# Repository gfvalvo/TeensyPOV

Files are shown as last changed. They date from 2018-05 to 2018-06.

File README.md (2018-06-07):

# TeensyPOV:

## POV Project on Teensy 3.2 - WORK IN PROGRESS

Library for POV (Persistence of Vision) display using Teensy 3.2 board and Adafuit DotStar LEDs (APA102). Descriptions of the hardware (including schematics and PWB) are in the Hardware folder.
The library is configured to support up to 48 LEDs in the string and up to 512 angular positions (~0.7 degree resolution). These positions are referred to as "segments" in the code and description below.
## Sample Images:
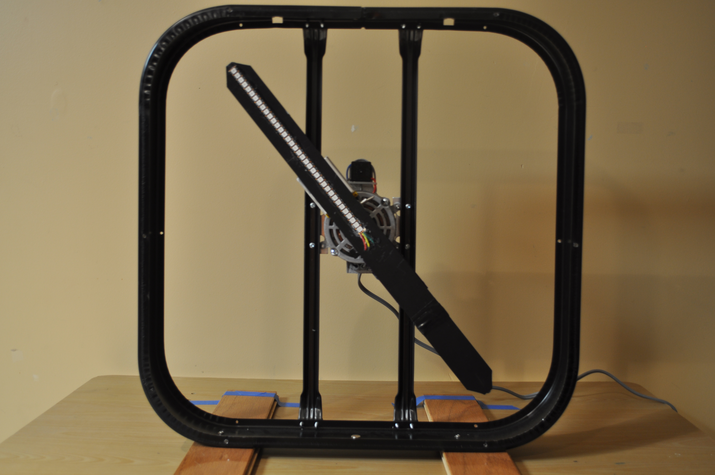
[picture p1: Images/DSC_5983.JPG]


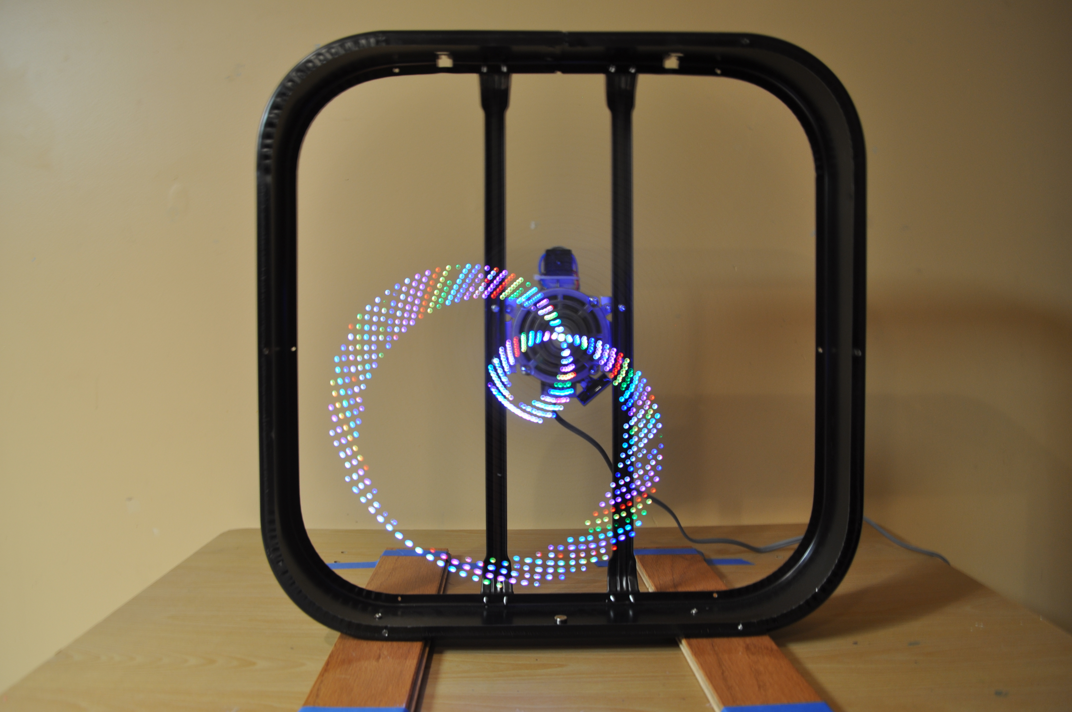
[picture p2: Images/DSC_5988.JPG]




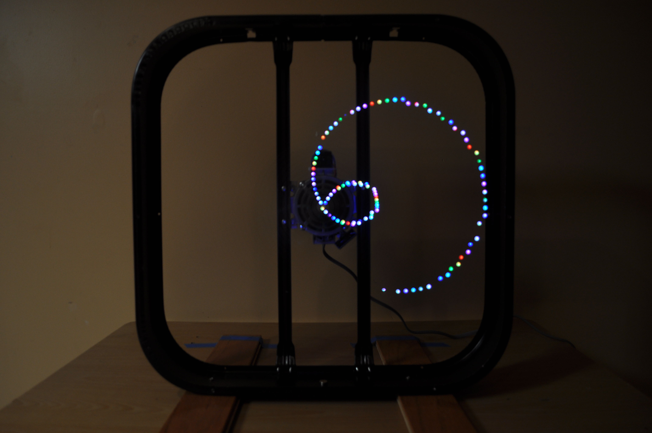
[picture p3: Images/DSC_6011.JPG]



[Video of POV in Action](https://youtu.be/CiRSouhlJos)

Note that interaction between the video's frame rate and the LED refresh rate causes some artifacts that aren't really there when you view the POV in person.

## Library Description:
Code in this library directly manipulates the Teensy processor's Programmable Interrupt Timers. Thus, it is incompatible with any code that uses these timers directly or indirectly via the Teensyduino IntervalTimer class.

All of the following class methods are demonstrated in the example sketches.
### Classes:
#### Class TeensyPOV
This class interfaces with the hardware and controls the LEDs to produce the POV display. All methods in this class are static. Thus there is no need to instantiate an object of this type.
#### Public TeensyPOV Members Functions:
****Initialize the T3.2 hardware needed for the POV Display****

    bool povSetup(uint8_t hPin, CRGB *ledPtr, uint8_t num)
**Arguments:**
 - **uint8_t hPin** - Hardware pin that the Hall Effect Sensor is connected to.
 - **CRGB \*ledPtr** - Pointer to an array of FastLED CRGB objects. These objects should be registered with the FastLED library before calling povSetup.
 - **uint8_t num** - Number LEDs in the array
 
****Check if Rotation Speed is High Enough for POV Display****

    bool rpmGood(void) 

****Get Number of Segments in the Currently Active POV Display.****

    uint16_t getNumSegments(void)

****Get Number of Teensy 3.2 PIT Ticks that Occurred During the Blade's last Rotation Period. On a 96 MHz T3.2 there are 48,000,000 Ticks per Second.****

    uint32_t getLastRotationCount(void)

****Set the color of an LED directly on the display.****

    void setPixel(uint16_t segment, uint16_t pixel, uint32_t value)

**Arguments:**

- **uint16_t segment** - Rotational segment of the LED, counted clockwise from Top Dead Center. Value between 0 and (Number of Segments)-1
- **uint16_t pixel** - Radial position of the LED, 0 = innermost.
- **uint32_t value** - Color of the LED expressed as index into current Palette.

#### Public TeensyPOV Data Members:

Defined constants that can be used in calls to TeensyPovDisplay methods (see **Class TeensyPovDisplay**):
```
static const uint8_t LOG_2_SEGMENTS = 1;
static const uint8_t LOG_4_SEGMENTS = 2;
static const uint8_t LOG_8_SEGMENTS = 3;
static const uint8_t LOG_16_SEGMENTS = 4;
static const uint8_t LOG_32_SEGMENTS = 5;
static const uint8_t LOG_64_SEGMENTS = 6;
static const uint8_t LOG_128_SEGMENTS = 7;
static const uint8_t LOG_256_SEGMENTS = 8;
static const uint8_t LOG_512_SEGMENTS = 9;

static const uint8_t COLOR_BITS_1 = 1;
static const uint8_t COLOR_BITS_2 = 2;
static const uint8_t COLOR_BITS_4 = 4;
static const uint8_t COLOR_BITS_8 = 8;
```
#### Class TeensyPovDisplay
This class allows the user to define POV images to be displayed. There can be multiple instances of this class defining different images. Only one is actively displayed at a time.
#### Public TeensyPovDisplay Members Functions:
****Constructor.****
````
TeensyPovDisplay()
````
****Load an empty TeensyPovDisplay object. Would be used if no bitmap image or text is desired. Pixels would be set by the main program using the setLed() method.****
````
void load(void)
````
****Load a TeensyPovDisplay object with a bit pattern image.****
````
void load(const LedArrayStruct *pattern)
````

**Arguments:**

- **const LedArrayStruct \*pattern** - Pointer to the image structure. The struct pointed to must be static or global. See below for definition of the LedArrayStruct structure.

****Load a TeensyPovDisplay object with text strings.****
````
void load(const DisplayStringSpec *strArray, uint8_t n)
````
**Arguments:**
- **const DisplayStringSpec \*strArray** - Pointer to an array of DisplayStringSpec structures. The array pointed to must be static or global. See below for definition of the DisplayStringSpec structure.
- **uint8_t n** - Number of DisplayStringSpec structures in the array.

****Load a TeensyPovDisplay object with a bit pattern image and text strings.****
````
void load(const LedArrayStruct *pattern, const DisplayStringSpec *strArray, uint8_t n)
````
**Arguments:**
- **const LedArrayStruct \*pattern** - Pointer to the image structure. The struct pointed to must be static or global. See below for definition of the LedArrayStruct structure.
- **const DisplayStringSpec \*strArray** - Pointer to an array of DisplayStringSpec structures. The array pointed to must be static or global. See below for definition of the DisplayStringSpec structure.
- **uint8_t n** - Number of DisplayStringSpec structures in the array.

****Display a TeensyPovDisplay object on the POV LEDs. Resets the duration and rotation timers.****
````
void activate()
````
****Refresh the TeensyPovDisplay object on the POV LEDs after changing text, bit image, palette, etc. Does not reset the duration and rotation timers****
````
void refresh()
````
****Set the POV parameters for a TeensyPovDisplay object that does not contain a bitmap image (i.e. a LedArrayStruct). Call this function after load() and before activate()****
````
void setDisplay(uint8_t logSeg, uint8_t cBits, uint16_t tdc, const uint32_t *colors)
````
**Arguments:**
- **uint8_t logSeg** - Log (base 2) of number of TDC segments. Use static constants defined by class TeensyPOV.
- **uint8_t cBits** - Number of color bits. Use static constants defined by class TeensyPOV.
- **uint16_t tdc** - Segment number to display when rotating blade hits Top Dead Center.
- **const uint32_t \*colors** - Pointer to array defining RGB color pallet. Array must have at least 2 ^ cBits elements. The array pointed to must be static or global.

****Set timing for dynamic TeensyPovDisplay objects. Calling this function is optional, all values are set to their default values by the load() method.****
````
void setTiming(uint32_t duration, uint32_t rotation, int16_t tdcDelta)
````
**Arguments:**
- **uint32_t duration** - Time (in milliseconds) before the object expires. Use zero (default) if object is permanent.
- **uint32_t rotation** - Time (in milliseconds) between changes in the Top Dead Center segment, causes display to rotate. Use zero (default)  for no rotation.
- **int16_t tdcDelta** - Adjustment to Top Dead Center segment every 'rotation' milliseconds. Use negative value for clockwise rotation and positive value for anti-clockwise. Has no effect if 'rotation' is zero.

****Determine if duration of TeensyPovDisplay object has expired and performs specified rotation****
````
bool update()
````
**Returns:** True if display's time has expired.

****Set optional callback function to be called when a TeensyPovDisplay object is activated.****
````
void setActivationCallback(void (*ptr)(TeensyPovDisplay *))
````
**Arguments:**
- **void (\*ptr)(TeensyPOV \*)** - Pointer to the function to be called. The function must take as an argument a pointer to the TeensyPOV object that was activated and return void.

****Set optional callback function to be called when a TeensyPovDisplay object is updated.****
````
void setUpdateCallback(void (*ptr)(TeensyPovDisplay *))
````
**Arguments:**
- **void (\*ptr)(TeensyPOV \*)** - Pointer to the function to be called. The function must take as an argument a pointer to the TeensyPOV object that was updated and return void.

****Set optional callback function to be called when a TeensyPovDisplay object expires.****
````
void setExpireCallback(void (*ptr)(TeensyPovDisplay *))
````
**Arguments:**
- **void (\*ptr)(TeensyPOV \*)** - Pointer to the function to be called. The function must take as an argument a pointer to the TeensyPOV object that expired and return void.

#### Enums and Structures Defined by TeensyPOV Class:
****Identifies text position at top or bottom of display.****
````
enum TextPosition {TOP, BOTTOM};
````
****Specification for character string to be displayed.****
````
struct DisplayStringSpec {
	const char *characters;
	TextPosition position;
	uint8_t topRow;
	uint8_t textColor;
	uint8_t backgroundColor;
	bool invert;
};
````
- **const char \*characters** - Pointer to null-terminated char array.
- **TextPosition position** - Position where text will be displayed.
- **uint8_t topRow** - LED position (from center) for top row of characters. Minimum value is 6.
- **uint8_t textColors** - Color of text expressed as index into current Palette.
- **uint8_t backgroundColor** - Background color for text expressed as index into current Palette.
- **bool invert** - Flip text on bottom so it appears right-side-up.

****Specification for bit map image to be displayed.****
````
struct LedArrayStruct {
	const uint32_t *array;
	const uint32_t *colors;
	uint32_t numColorBits;
	uint8_t logNumSegments;
	uint32_t columns;
	uint32_t tdcDisplaySegment;
};
````
- **const uint32_t \*array** - Pointer to 2-dimensional bit map array. See below for specification. The array pointed to must be static or global.
- **const uint32_t \*colors** - Pointer to array defining RGB color pallet. Array must have at least 2 ^ numColorBits elements. The array pointed to must be static or global. 
- **uint32_t numColorBits** - Number of color bits. Use static constants defined by class TeensyPOV.
- **uint8_t logNumSegments** - Log (base 2) of number of TDC segments. Use static constants defined by class TeensyPOV.
- **uint32_t columns** - Number of columns in the array.
- **uint32_t tdcDisplaySegment** - Segment number to display when rotating blade hits Top Dead Center.
- 
****Bit Map Array****

The number of Rows is equal to the number of segments in the display. The number of Columns depends on how many color bits are used to represent each LED. For example, with 36 LEDs, Two Bits / LED, and 256 Segments:

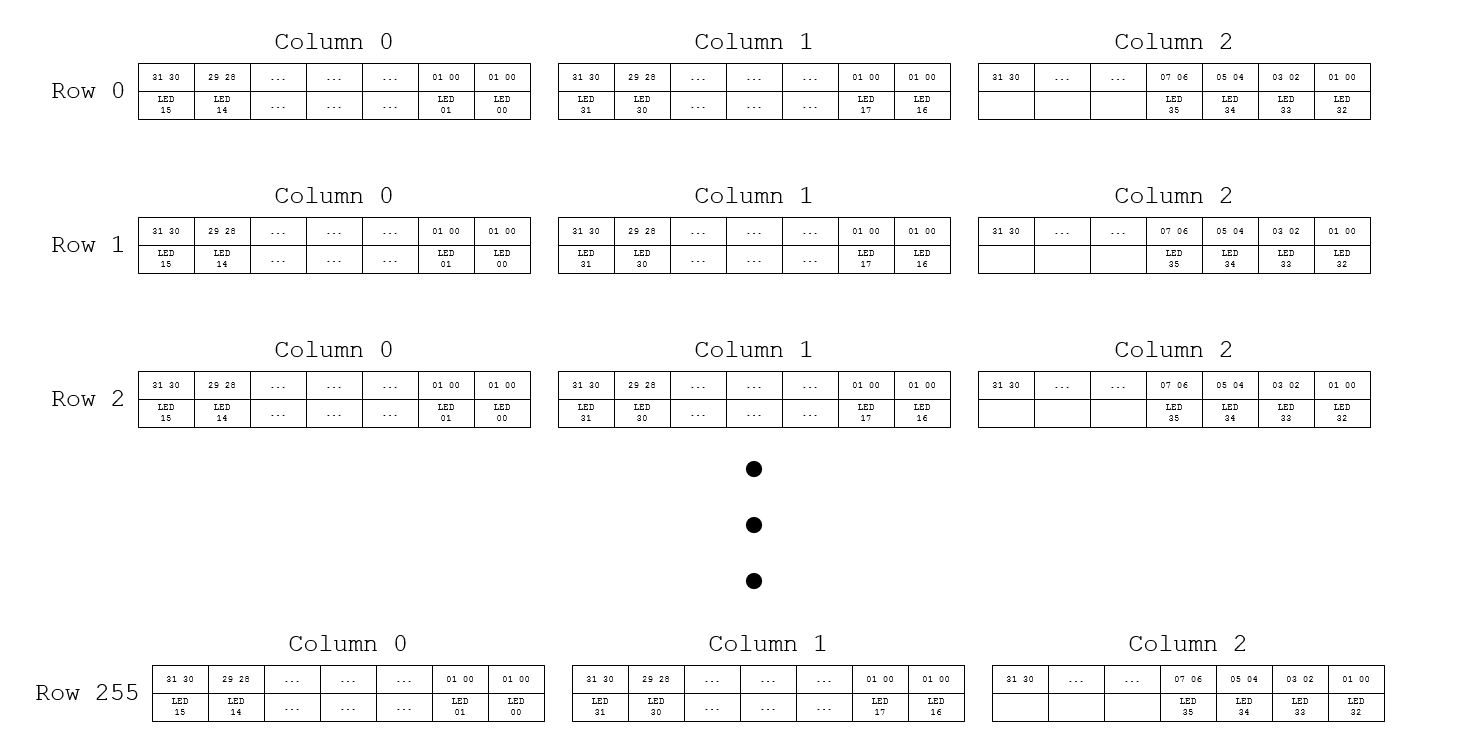
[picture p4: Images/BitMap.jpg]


## POV Hardware:
### Block Diagram:
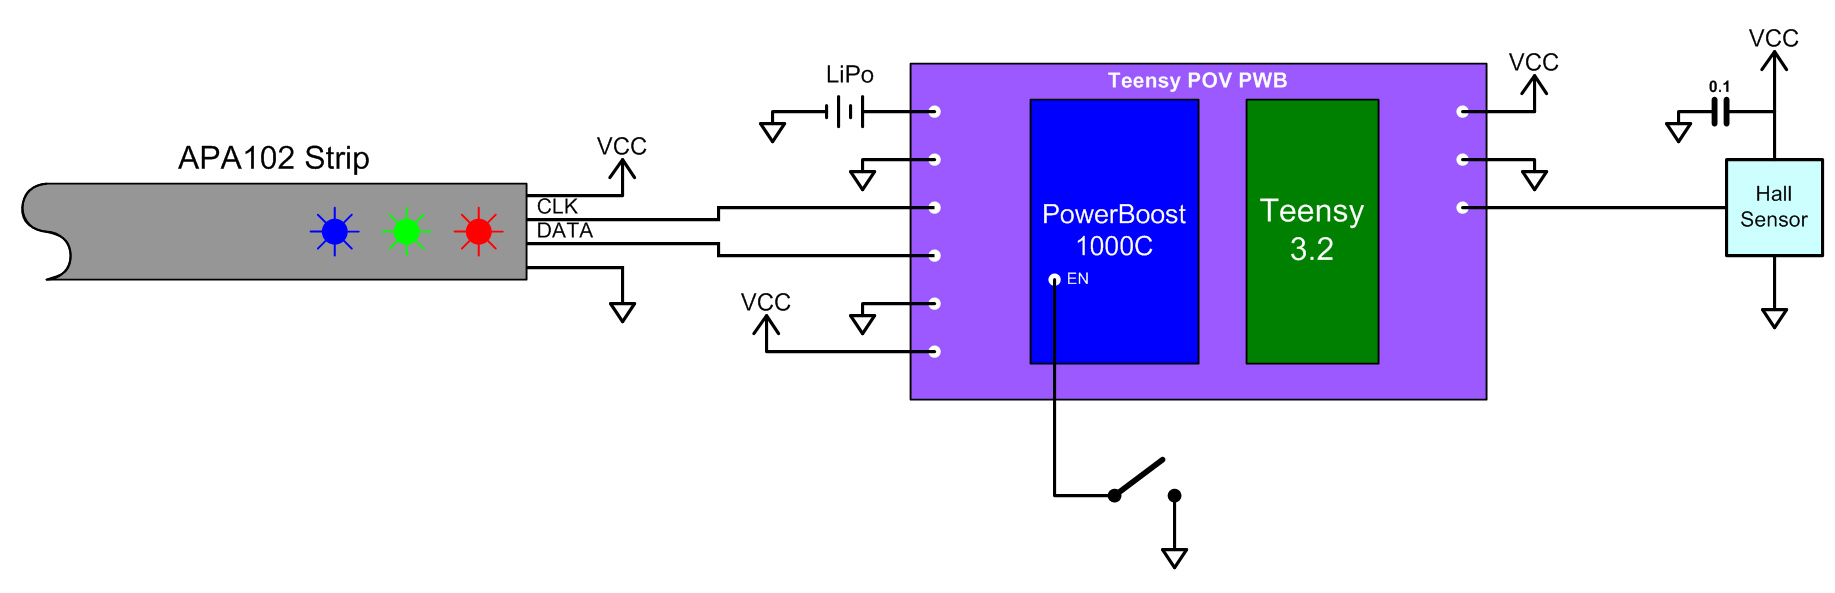
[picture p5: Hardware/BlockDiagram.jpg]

### PWB Schematic:
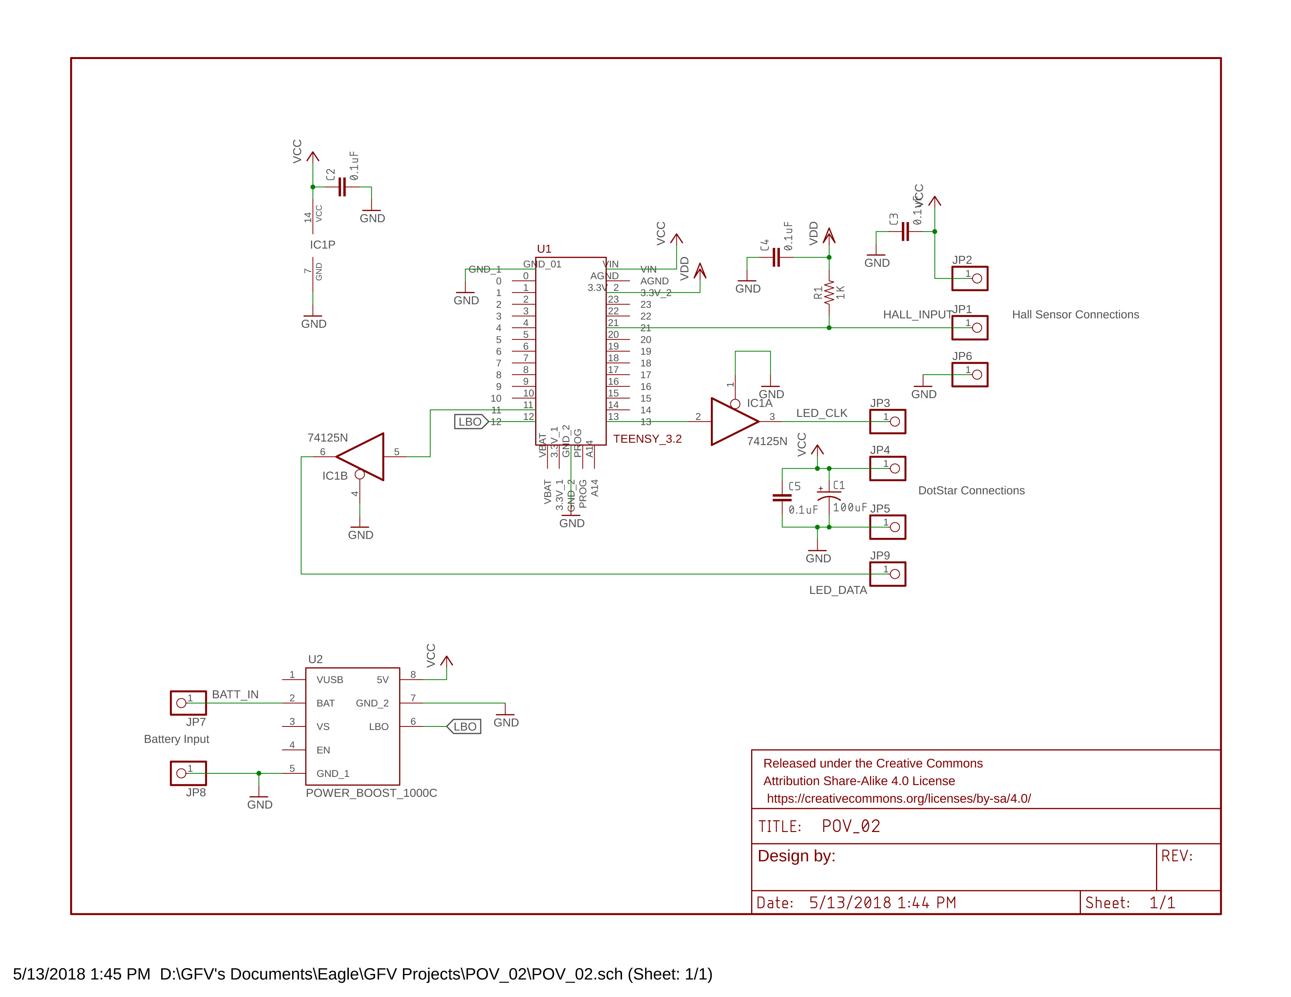
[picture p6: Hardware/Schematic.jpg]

### PWB Layout:
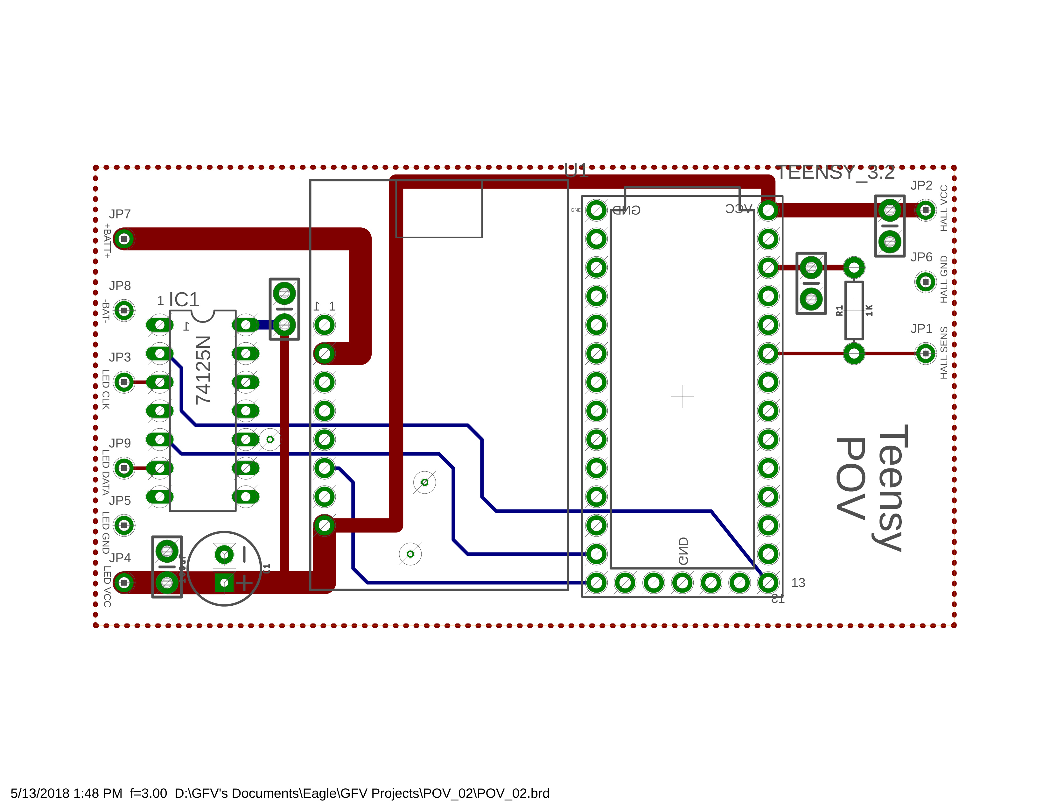
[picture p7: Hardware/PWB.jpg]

### Populated PWB:
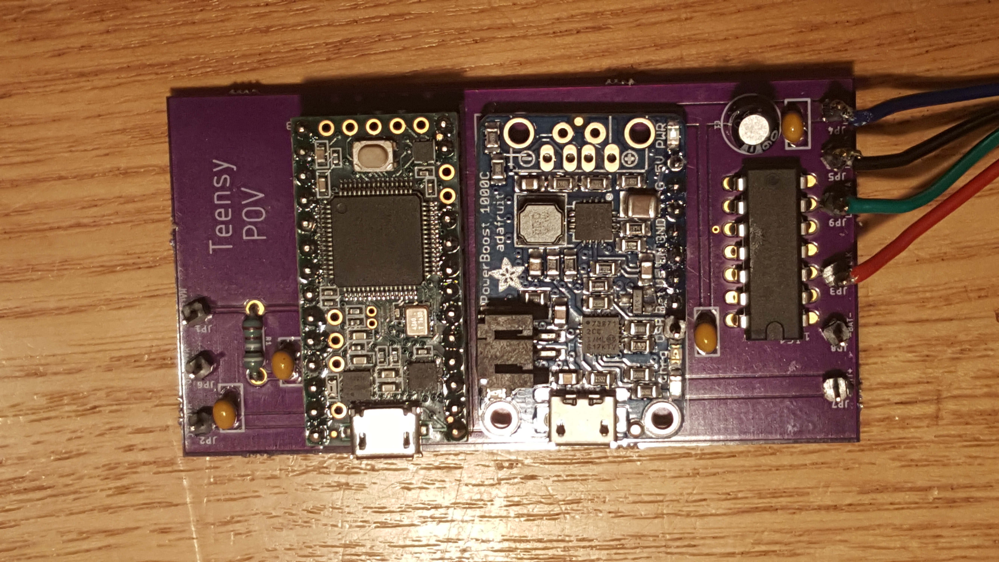
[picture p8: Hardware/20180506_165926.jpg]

### Blank Blade with Hub Mounted:
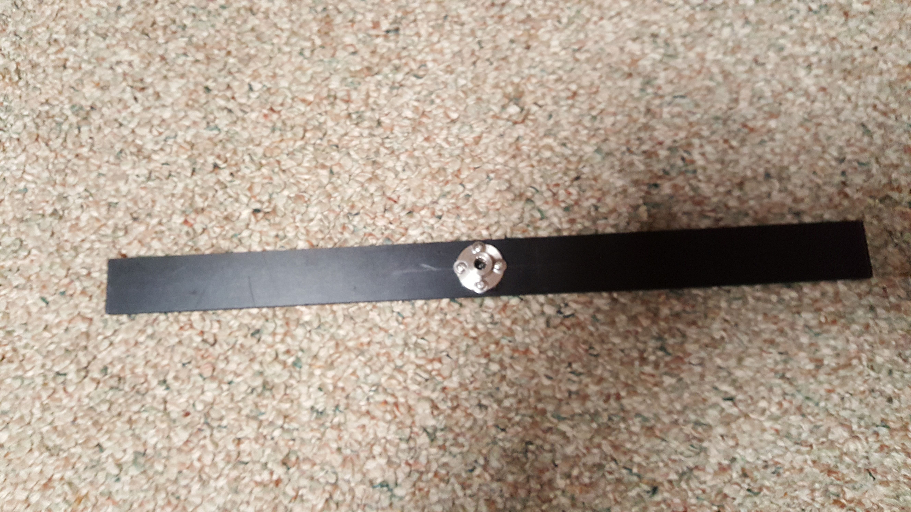
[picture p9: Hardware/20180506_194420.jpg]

### Backside Components:

### Hall Sensor:
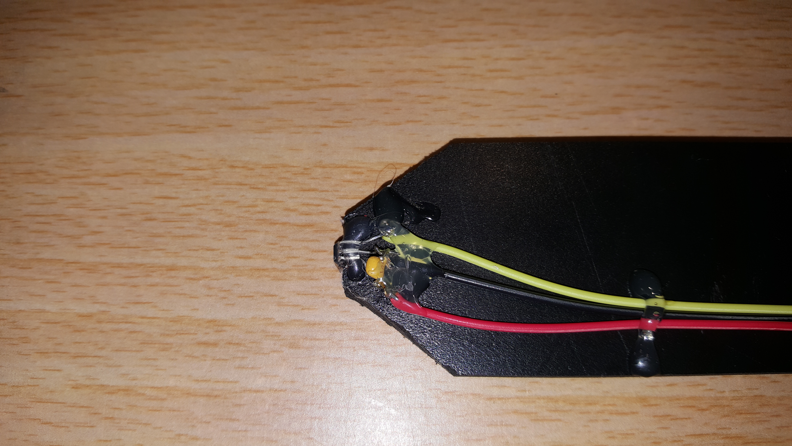
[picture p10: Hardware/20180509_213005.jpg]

### LEDs Mounted:

### Start with this Fan
[$20 From Target](https://www.target.com/p/holmes-174-20-3-speed-box-fan-black-hbf2001d-b/-/A-15024768)
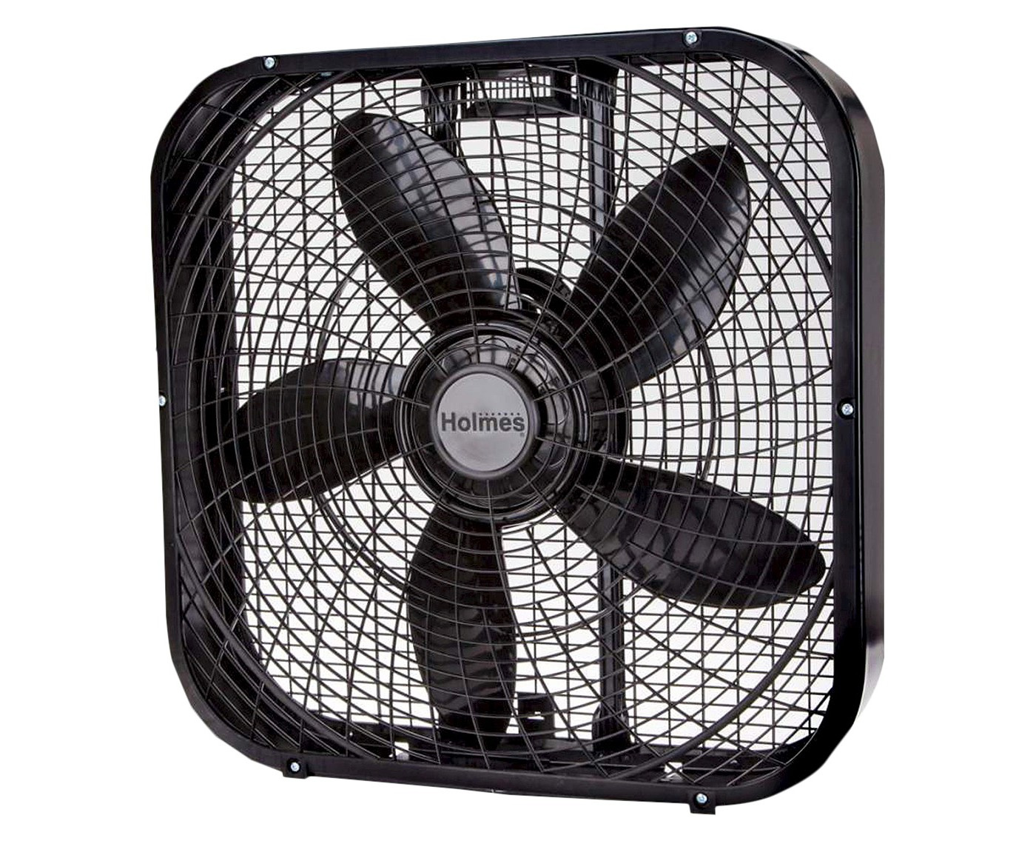
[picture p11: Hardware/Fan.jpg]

### Reverse these Rails as Shown to Push Motor Further out the Back.
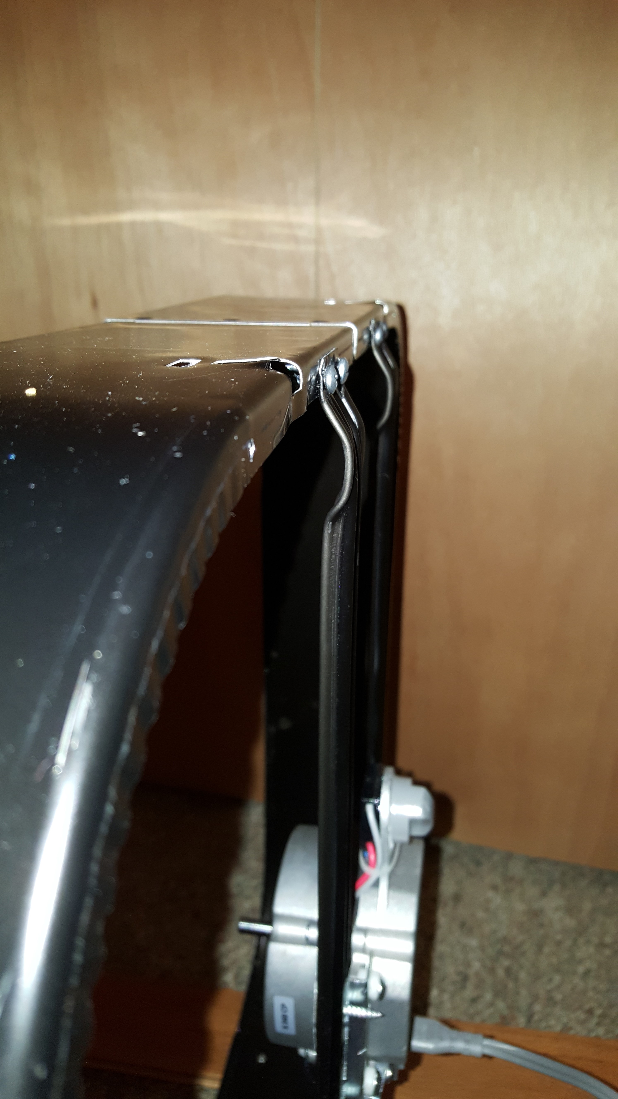
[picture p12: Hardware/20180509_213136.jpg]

### Reverse these Brackets as Shown to Push Motor Further out the Back.
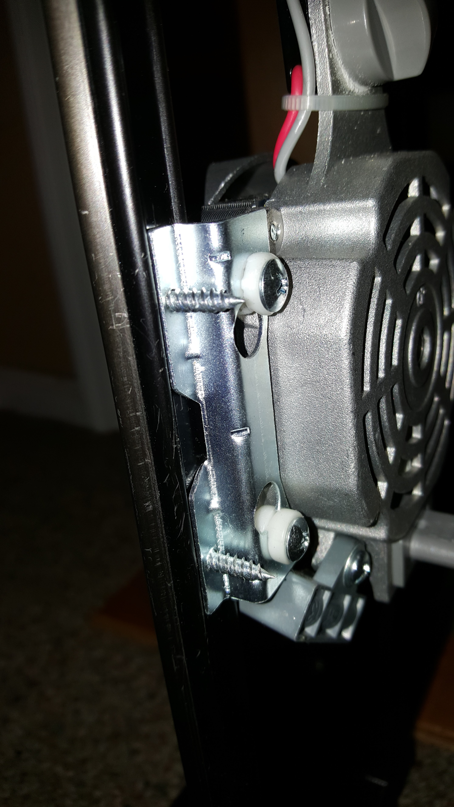
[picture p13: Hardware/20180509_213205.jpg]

### Hall device senses magnet and signal processor that LEDs are in the Top Dead Center position.


# CREDITS
I shamelessly appropriated the Dot Matrix characters that Arduino Forum user @Jiggy-Ninja developed for his POV project posted here:
[Dram Queen](https://forum.arduino.cc/index.php?topic=493075.0)

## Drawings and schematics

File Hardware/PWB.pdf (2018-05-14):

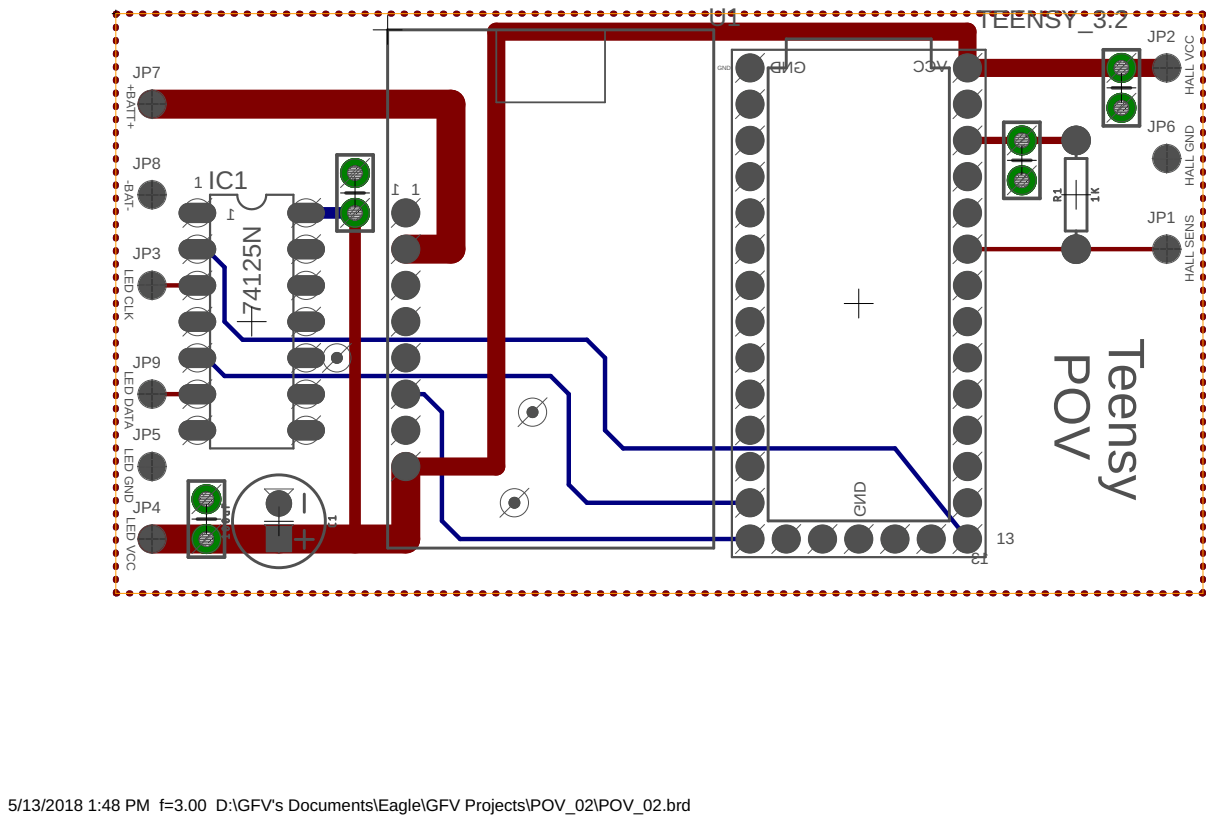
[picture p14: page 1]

+BATT+ -BAT- LED CLK LED DATA LED GND LED V

5/13/2018 1:48 PM f=3.00 D:\GFV's Documents\Eagle\GFV Projects\POV_02\POV_02.brd

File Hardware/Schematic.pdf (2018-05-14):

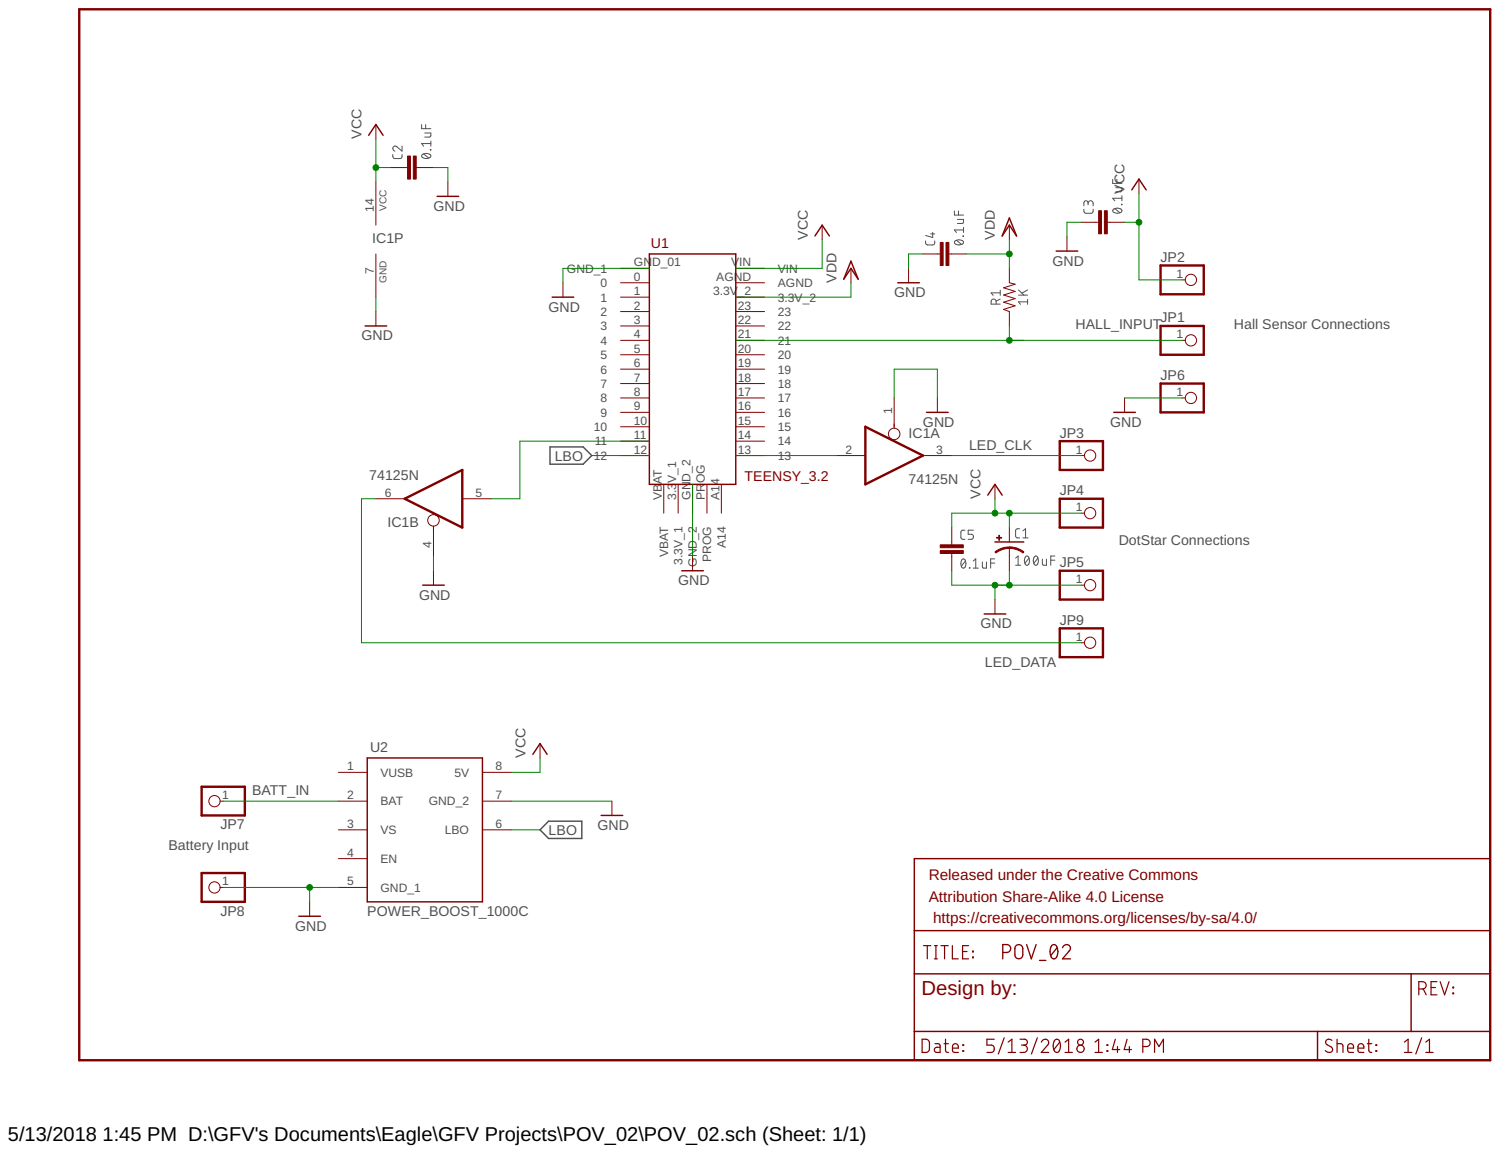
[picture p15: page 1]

Released under the Creative Commons Attribution Share-Alike 4.0 License

https://creativecommons.org/licenses/by-sa/4.0/

5/13/2018 1:45 PM D:\GFV's Documents\Eagle\GFV Projects\POV_02\POV_02.sch (Sheet: 1/1)

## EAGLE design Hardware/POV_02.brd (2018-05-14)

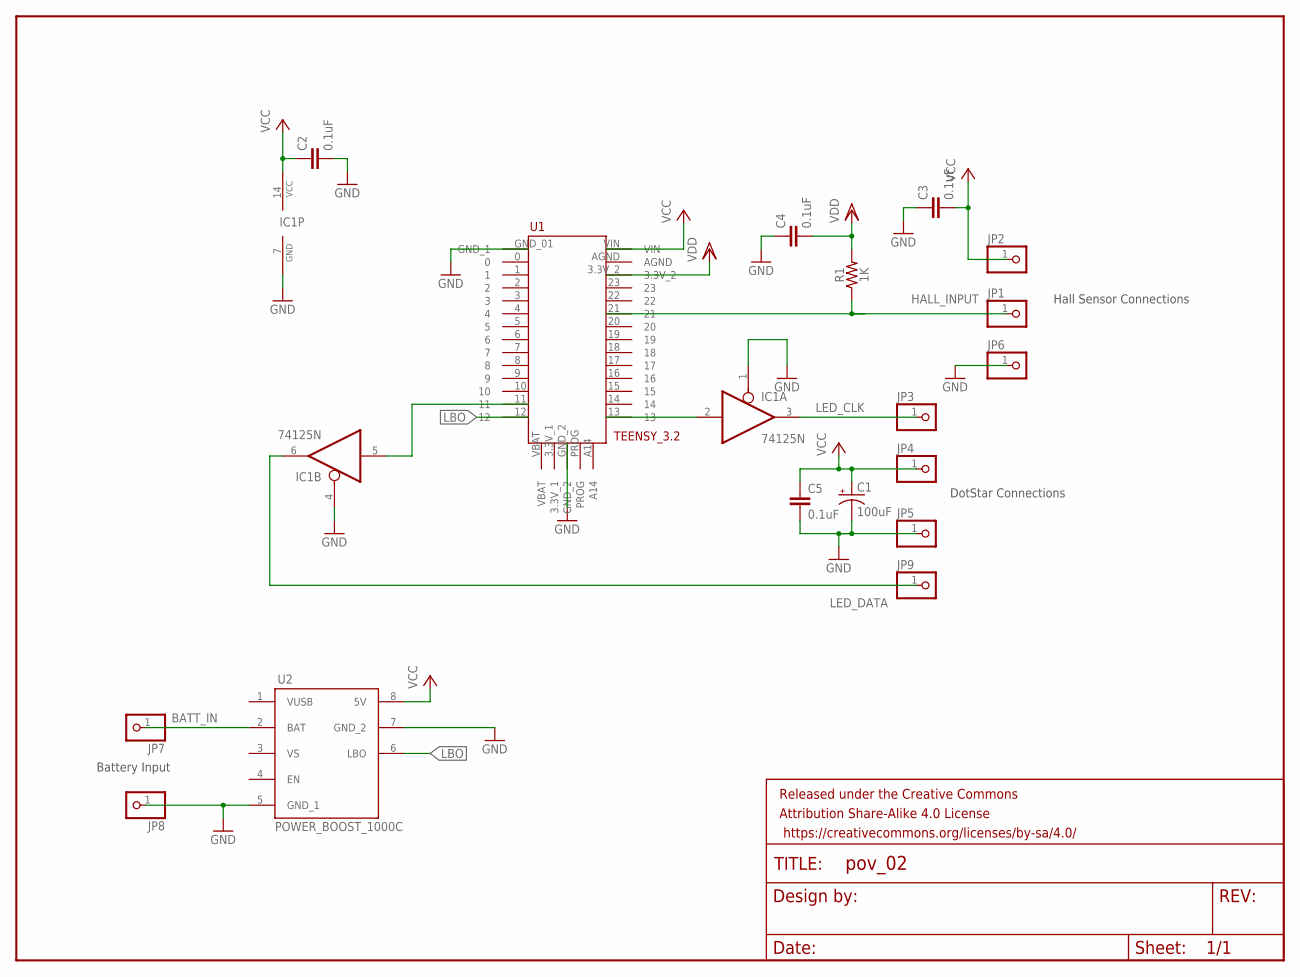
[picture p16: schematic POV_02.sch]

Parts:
C1: 100uF; CPOL-RADIAL-2.5MM-6.5MM
C2, C3, C4, C5: 0.1uF; CAP-PTH-SMALL-KIT
FRAME1: FRAME-LETTERNO_PACKAGE; DUMMY
IC1: 74125N; DIL14
JP1, JP2, JP3, JP4, JP5, JP6, JP7, JP8, JP9: HEADER-1X1ROUND; 1X01_ROUND
R1: 1K; AXIAL-0.3
U1: TEENSY_3.2; TEENSEY_3.2
U2: POWER_BOOST_1000C

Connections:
BATT_IN: JP7.1, U2.2 (BAT)
GND: C1.2 (-), C2.2, C3.1, C4.1, C5.2, IC1.1 (OE), IC1.4 (OE), IC1.7 (GND), JP5.1, JP6.1, JP8.1, U1.GND_01 (GND_1), U1.GND_2, U2.5 (GND_1), U2.7 (GND_2)
HALL_INPUT: JP1.1, R1.P$1 (1), U1.21
LBO: U1.12, U2.6 (LBO)
LED_CLK: IC1.3 (O), JP3.1
LED_DATA: IC1.6 (O), JP9.1
unnamed: IC1.2 (I), U1.13
unnamed: IC1.5 (I), U1.11
VCC: C1.1 (+), C2.1, C3.2, C5.1, IC1.14 (VCC), JP2.1, JP4.1, U1.VIN, U2.8 (5V)
VDD: C4.2, R1.P$2 (2), U1.3.3V_2

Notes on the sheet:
Battery Input
DotStar Connections
Hall Sensor Connections

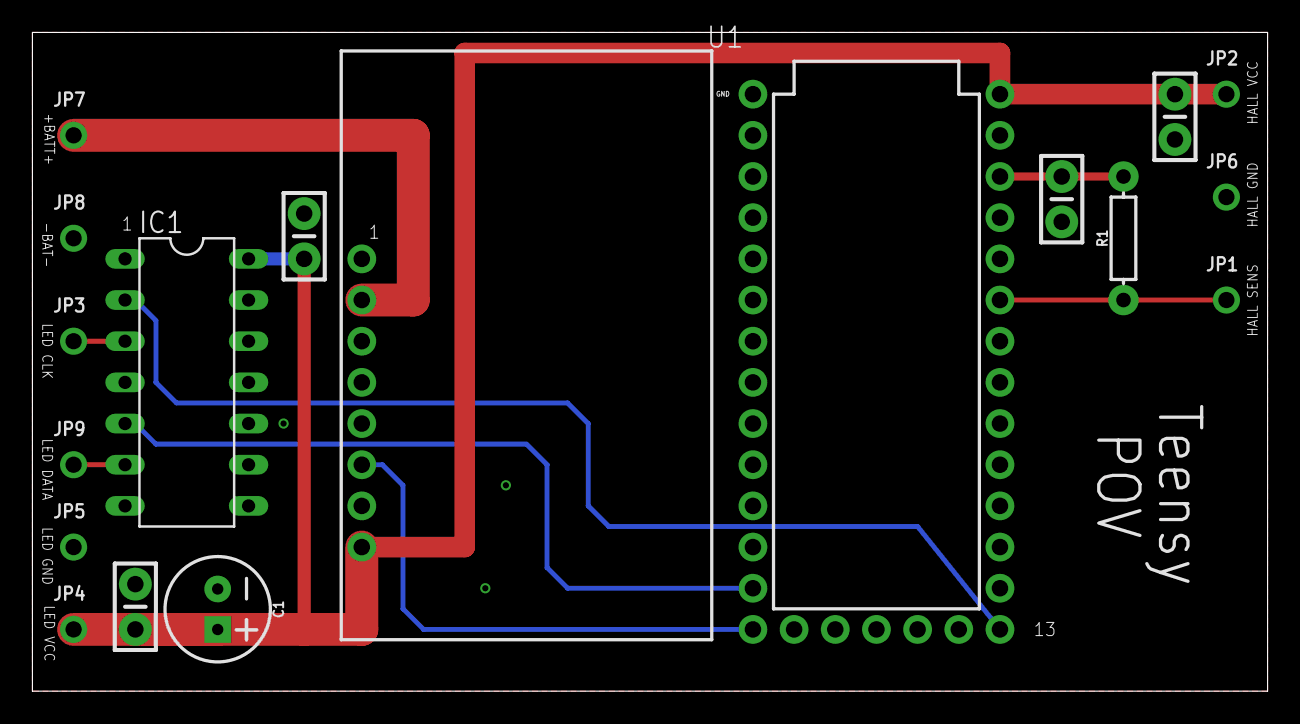
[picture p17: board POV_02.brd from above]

Board: 2 copper layers, 76.2 x 40.6 mm, 19 parts (0 on the bottom side), 10 nets.

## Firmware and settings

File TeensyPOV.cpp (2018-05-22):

/*
 * TeensyPOV.cpp
 *
 *  Created on: Apr 28, 2018
 *      Author: GFV
 */
#include "TeensyPOV.h"
#include "textCharacters.h"

static void mainTdcISR(void);

uint8_t TeensyPOV::pixelsPerWord;
uint32_t TeensyPOV::numLeds;
CRGB * TeensyPOV::leds;

KINETISK_PIT_CHANNEL_t * TeensyPOV::rpmTimer;
KINETISK_PIT_CHANNEL_t * TeensyPOV::segmentTimer;
#ifdef SIMULATE_RPM
KINETISK_PIT_CHANNEL_t * TeensyPOV::tdcSimulator;
#endif  // SIMULATE_RPM

void (*TeensyPOV::funct_table[4])() = {TeensyPOV::dummy_funct, TeensyPOV::dummy_funct, TeensyPOV::dummy_funct, TeensyPOV::dummy_funct};
void (*TeensyPOV::tdcInteruptVector)() = TeensyPOV::dummy_funct;

volatile uint8_t TeensyPOV::currentLogNumSegments = 1;
volatile uint32_t TeensyPOV::segmentArray[maxNumSegments][maxColumns];
volatile uint32_t TeensyPOV::colorArray[1 << maxNumColorBits];
volatile uint32_t TeensyPOV::currentNumColorBits = 0;
volatile uint32_t TeensyPOV::currentNumSegments = 1 << currentLogNumSegments;
volatile uint32_t TeensyPOV::currentSegmentMask = currentNumSegments - 1;
volatile uint32_t TeensyPOV::currentColorMask;
volatile uint32_t TeensyPOV::goodRpmCount;
volatile uint32_t TeensyPOV::currentDisplaySegment;
volatile uint32_t TeensyPOV::currentTdcDisplaySegment = 0;
volatile uint32_t TeensyPOV::updateTdcDisplaySegment = currentTdcDisplaySegment;
volatile uint32_t TeensyPOV::lastRpmTimerReading;
volatile uint8_t TeensyPOV::hallPin;
#ifdef DEBUG_MODE
volatile bool TeensyPOV::segmentTimerIsrFire = false;
volatile bool TeensyPOV::rpmTimerIsrFire = false;
volatile bool TeensyPOV::missedSegment = false;
volatile uint8_t TeensyPOV::tdcIsrFire = 0;
volatile uint32_t TeensyPOV::lastSegment;
#endif  // DEBUG_MODE

bool TeensyPOV::povSetup(uint8_t hPin, CRGB *ledPtr, uint8_t num) {
	/*
	 * Initialize the POV setup.
	 * Parameters:
	 * 	uint8_t hPin -- Pin that the (active low) Hall Effect sensor is connected to.
	 *
	 * 	CRGB *ledPtr -- Pointer to the array of FastLED CRGB objects. Before calling this method, the CRBG objects should be registered
	 * 		with FastLED using the FastLED.addLeds() method.
	 *
	 * 	uint8_t num -- Number of LEDs
	 *
	 * 	Returns:
	 * 		true if num < maxNumLeds
	 */
	const uint8_t rpmTimerIndex = 0;
	const uint8_t segmentTimerIndex = 1;

	const uint8_t rpmTimerInterruptPriority = 128;
	const uint8_t segmentTimerInterruptPriority = 128;

	if (num > maxNumLeds) {
		return false;
	}
	hallPin = hPin;
	leds = ledPtr;
	numLeds = num;
	allLedsOff(); // Initialize LEDs and set all off

	// Enable Periodic Interrupt Timers (PIT) - from PJRC Teensy IntervalTimer.cpp code
	SIM_SCGC6 |= SIM_SCGC6_PIT;
	// solves timing problem on Teensy 3.5
	__asm__ volatile("nop");
	PIT_MCR = 1;

	// Assign PITs
	rpmTimer = KINETISK_PIT_CHANNELS + rpmTimerIndex;
	segmentTimer = KINETISK_PIT_CHANNELS + segmentTimerIndex;

	// Configure RPM Watchdog PIT
	rpmTimer->TCTRL = 0;							// Disable PIT
	rpmTimer->TFLG = 1;								// Clear interrupt flag
	rpmTimer->LDVAL = rpmCycles;					// Set count down value
	funct_table[rpmTimerIndex] = rpmTimerIsr;		// Set ISR
	NVIC_SET_PRIORITY(IRQ_PIT_CH0 + rpmTimerIndex, rpmTimerInterruptPriority);// Set interrupt priority
	NVIC_ENABLE_IRQ(IRQ_PIT_CH0 + rpmTimerIndex);			// Enable interrupt

	// Configure segmentTimer PIT to set LEDs at each rotation position
	segmentTimer->TCTRL = 0;		// Disable PIT will be enabled in tdcISR()
	segmentTimer->TFLG = 1;			// Clear interrupt flag
	funct_table[segmentTimerIndex] = segmentTimerIsr;		// Set ISR
	NVIC_SET_PRIORITY(IRQ_PIT_CH0 + segmentTimerIndex,
			segmentTimerInterruptPriority);	// Set interrupt priority
	NVIC_ENABLE_IRQ(IRQ_PIT_CH0 + segmentTimerIndex);		// Enable interrupt

#ifdef SIMULATE_RPM
	// Set up timer interrupt to simulate Hall sensor (Top Dead Center)
	const uint8_t tdcSimulatorTimerIndex = 3;
	const uint8_t tdcSimulatorInterruptPriority = 128;

	tdcSimulator = KINETISK_PIT_CHANNELS + tdcSimulatorTimerIndex;
	tdcSimulator->TCTRL = 0;// Disable PIT
	tdcSimulator->TFLG = 1;// Clear interrupt flag
	tdcSimulator->LDVAL = tdcSimulatorCycles;// Set count down value
	funct_table[tdcSimulatorTimerIndex] = mainTdcISR;// Set ISR
	NVIC_SET_PRIORITY(IRQ_PIT_CH0 + tdcSimulatorTimerIndex,
			tdcSimulatorInterruptPriority);// Set interrupt priority
	NVIC_ENABLE_IRQ(IRQ_PIT_CH0 + tdcSimulatorTimerIndex);// Enable interrupt
	tdcSimulator->TCTRL = 3;

#else
	// Set up interrupt for Hall sensor (Top Dead Center)
	pinMode(hallPin, INPUT_PULLUP);
	attachInterrupt(hallPin, mainTdcISR, FALLING);
#endif  // SIMULATE_RPM

	setParameters(1, 1, 0);
	return true;
}

void TeensyPOV::loadPattern(const LedArrayStruct *patternStruct) {
	uint32_t row, column;

	for (row = 0; row < currentNumSegments; row++) {
		for (column = 0; column < patternStruct->columns; column++) {
			segmentArray[row][column] = *(patternStruct->array
					+ row * patternStruct->columns + column);
		}
	}
}

bool TeensyPOV::rpmGood() {
	/*
	 * Report if POV blade is spinning at sufficient rotational speed
	 * Parameters:
	 *			None
	 *  Returns:
	 * 			true - speed is good
	 * 			false - otherwise
	 */
	return (tdcInteruptVector == tdcIsrActive);
}

uint16_t TeensyPOV::getNumSegments() {
	return currentNumSegments;
}

uint32_t TeensyPOV::getLastRotationCount() {
	/*
	 * Get duration of last POV blade rotation in units of PIT ticks.
	 * On a Teensy 3.2 there are 48,000,000 PIT ticks per second.
	 * This value can be used to compute the blade's rotational speed.
	 *	Parameters:
	 *			N/A
	 *	Returns:
	 * 			Count of PIT ticks (uint32_t)
	 */
	return rpmCycles - lastRpmTimerReading;
}

void TeensyPOV::setPixel(uint16_t segment, uint16_t pixel, uint32_t value) {
	/*
	 * Set a LED directly on the display.
	 * Parameters:
	 * 	uint16_t segment -- Rotational segment of the LED, counted clockwise from Top Dead Center. Value between 0 and (Number of Segments)-1
	 *
	 * 	uint16_t led -- Radial position of the LED, 0 = innermost.
	 *
	 * 	uint32_t value -- Color of the LED expressed as index into current Palette.
	 *
	 * Returns:
	 * 		N/A
	 */
	uint8_t pixelWord, pixelShift;
	uint32_t pixelMask;

	pixelWord = pixel / pixelsPerWord;
	pixelShift = (pixel % pixelsPerWord) * currentNumColorBits;
	pixelMask = currentColorMask << pixelShift;
	value <<= pixelShift;
	value &= pixelMask;

	segmentArray[segment][pixelWord] &= (~pixelMask);
	segmentArray[segment][pixelWord] |= value;
}



void TeensyPOV::loadColors(const uint32_t *cPtr) {
	uint16_t index1;
	for (index1 = 0; index1 < (1 << currentNumColorBits); index1++) {
		colorArray[index1] = *(cPtr + index1);
	}
}
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

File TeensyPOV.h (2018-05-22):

/*
 * TeensyPOV.h
 *
 *  Created on: Apr 28, 2018
 *      Author: GFV
 */

#ifndef TEENSYPOV_H_
#define TEENSYPOV_H_

//#define SIMULATE_RPM
//#define DEBUG_MODE

#include <Arduino.h>
#define FASTLED_INTERNAL
#include "FastLED.h"

enum TextPosition {
	TOP, BOTTOM
};

struct LedArrayStruct {
	const uint32_t *array;
	const uint32_t *colors;
	uint32_t numColorBits;
	uint8_t logNumSegments;
	uint32_t columns;
	uint32_t tdcDisplaySegment;
};

struct DisplayStringSpec {
	const char *characters;
	TextPosition position;
	uint8_t topRow;
	uint8_t textColor;
	uint8_t backgroundColor;
	bool invert;
};

class TeensyPOV {
	friend class TeensyPovDisplay;
public:
	static const uint8_t LOG_2_SEGMENTS = 1;
	static const uint8_t LOG_4_SEGMENTS = 2;
	static const uint8_t LOG_8_SEGMENTS = 3;
	static const uint8_t LOG_16_SEGMENTS = 4;
	static const uint8_t LOG_32_SEGMENTS = 5;
	static const uint8_t LOG_64_SEGMENTS = 6;
	static const uint8_t LOG_128_SEGMENTS = 7;
	static const uint8_t LOG_256_SEGMENTS = 8;
	static const uint8_t LOG_512_SEGMENTS = 9;

	static const uint8_t COLOR_BITS_1 = 1;
	static const uint8_t COLOR_BITS_2 = 2;
	static const uint8_t COLOR_BITS_4 = 4;
	static const uint8_t COLOR_BITS_8 = 8;

	static bool povSetup(uint8_t, CRGB *, uint8_t);
	static bool rpmGood(void);
	static uint16_t getNumSegments(void);
	static uint32_t getLastRotationCount(void);
	static void setPixel(uint16_t, uint16_t, uint32_t);
	static void (*funct_table[4])();
	static void (*tdcInteruptVector)();

#ifdef DEBUG_MODE
	static void debugPrint(void);
#endif 		//DEBUG_MODE

private:
	static void dummy_funct(void);
	static void rpmTimerIsr(void);
	static void segmentTimerIsr(void);
	static void tdcIsrInit(void);
	static void tdcIsrActive(void);
	static void updateLeds(void);
	static void allLedsOff(void);
	static void loadPattern(const LedArrayStruct *);
	static void loadColors(const uint32_t *);
	static void setParameters(uint8_t, uint8_t, uint16_t);
	static void loadString(const char *, TextPosition, uint8_t, uint8_t,
			uint8_t, bool);

#ifndef SIMULATE_RPM
	static const uint32_t maxRevolutionPeriod = 100000UL; // Only run LEDs when > 10 revs / sec (600 RPM)
#else
	static const uint32_t maxRevolutionPeriod = 30000000UL;
#endif  //SIMULATE_RPM

	static const uint32_t rpmCycles = (F_BUS / 1000000UL) * maxRevolutionPeriod
			- 1;

	static const uint32_t maxNumLeds = 48;
	static const uint32_t maxNumColorBits = COLOR_BITS_8;
	static const uint32_t bitCountLoad = 0x80000000;
	static const uint32_t maxNumSegments = 1 << LOG_512_SEGMENTS;
	static const uint32_t bitsPerSegment = maxNumLeds * maxNumColorBits;
	static const uint32_t bitsPerWord = 32;
	static const uint32_t maxColumns = (bitsPerSegment / bitsPerWord);
	static const uint8_t maxTextChars = maxNumSegments / (2 * 7);
	static const uint8_t minGoodRpmCount = 2;

	static uint8_t pixelsPerWord;
	static uint32_t numLeds;
	static CRGB *leds;

	static KINETISK_PIT_CHANNEL_t *rpmTimer;
	static KINETISK_PIT_CHANNEL_t *segmentTimer;
#ifdef SIMULATE_RPM
	static const uint32_t tdcSimulatorCycles = (F_BUS / 1000000UL) * 50000UL
			- 1;
	static KINETISK_PIT_CHANNEL_t *tdcSimulator;
#endif  // SIMULATE_RPM

	volatile static uint8_t currentLogNumSegments;
	volatile static uint32_t segmentArray[maxNumSegments][maxColumns];
	volatile static uint32_t colorArray[1 << maxNumColorBits];
	volatile static uint32_t currentNumColorBits;
	volatile static uint32_t currentNumSegments;
	volatile static uint32_t currentSegmentMask;
	volatile static uint32_t currentColorMask;
	volatile static uint32_t goodRpmCount;
	volatile static uint32_t currentDisplaySegment;
	volatile static uint32_t currentTdcDisplaySegment;
	volatile static uint32_t updateTdcDisplaySegment;
	volatile static uint32_t lastRpmTimerReading;
	volatile static uint8_t hallPin;
#ifdef DEBUG_MODE
	volatile static bool segmentTimerIsrFire;
	volatile static bool rpmTimerIsrFire;
	volatile static bool missedSegment;
	volatile static uint8_t tdcIsrFire;
	volatile static uint32_t lastSegment;
#endif  // DEBUG_MODE
};

#endif /* TEENSYPOV_H_ */

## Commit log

2018-05-14 Updated Read Me
    [POV_02.brd, POV_02.sch]
2018-05-22 Fix to handle 8 bits / pixel
    [TeensyPOV.cpp, TeensyPOV.h]

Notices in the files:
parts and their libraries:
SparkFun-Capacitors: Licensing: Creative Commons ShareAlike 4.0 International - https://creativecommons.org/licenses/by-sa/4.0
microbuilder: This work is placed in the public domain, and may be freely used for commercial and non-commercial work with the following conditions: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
